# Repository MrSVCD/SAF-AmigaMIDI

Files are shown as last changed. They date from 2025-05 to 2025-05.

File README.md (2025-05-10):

# SAF-AmigaMIDI

## Not verified

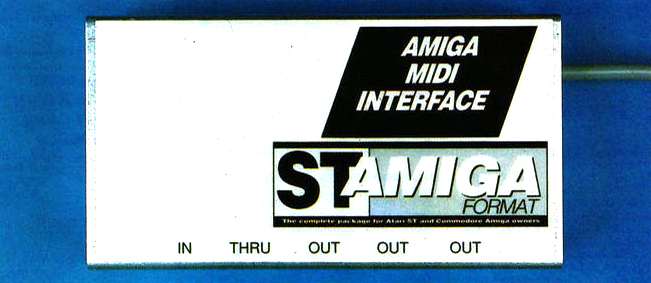
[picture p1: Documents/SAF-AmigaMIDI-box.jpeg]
Images


A somewhat faithful recreation of the Amiga MIDI interface from
"ST Amiga Format" issue 5

In the folder [CNC-version/](CNC-version/) is a mainly single sided design that
is targeting toner transfer, home photolithography and CNC milling. There are a
place for a optional L7805 voltage regulator. There are only two jumper wires in
this design that is shown as upper PCB layer.

Original article [Documents/SAF-AmigaMIDI.pdf](Documents/SAF-AmigaMIDI.pdf)

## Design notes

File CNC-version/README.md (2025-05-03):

# SAF-AmigaMIDI-CNC

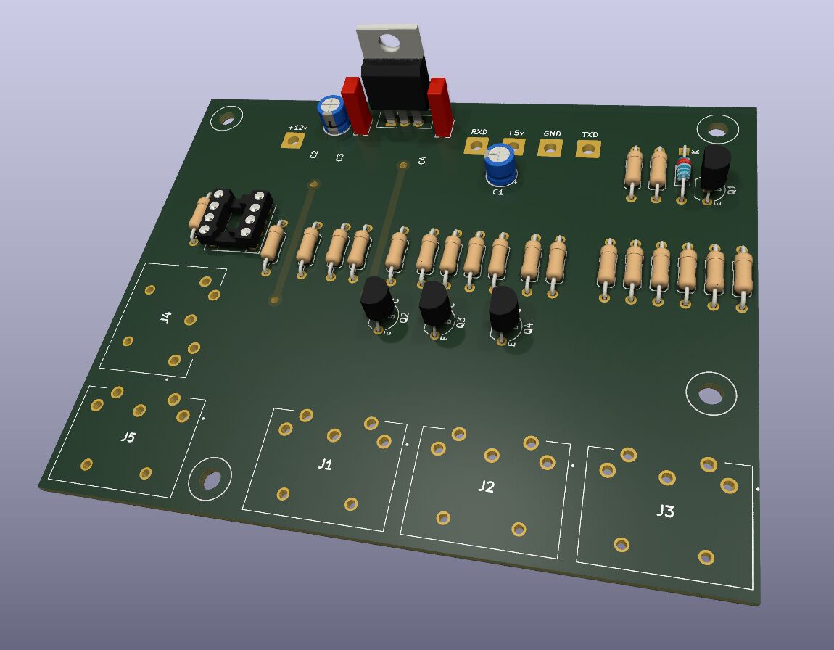
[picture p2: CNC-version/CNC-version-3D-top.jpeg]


This version is for making the midi interface at home.

It is single sided with two jumper wires (the wires is shown as the top copper
layer) there are also a optional voltage regulator spot.

It is also made to fit on a 100✕80mm, Half a Eurocard.

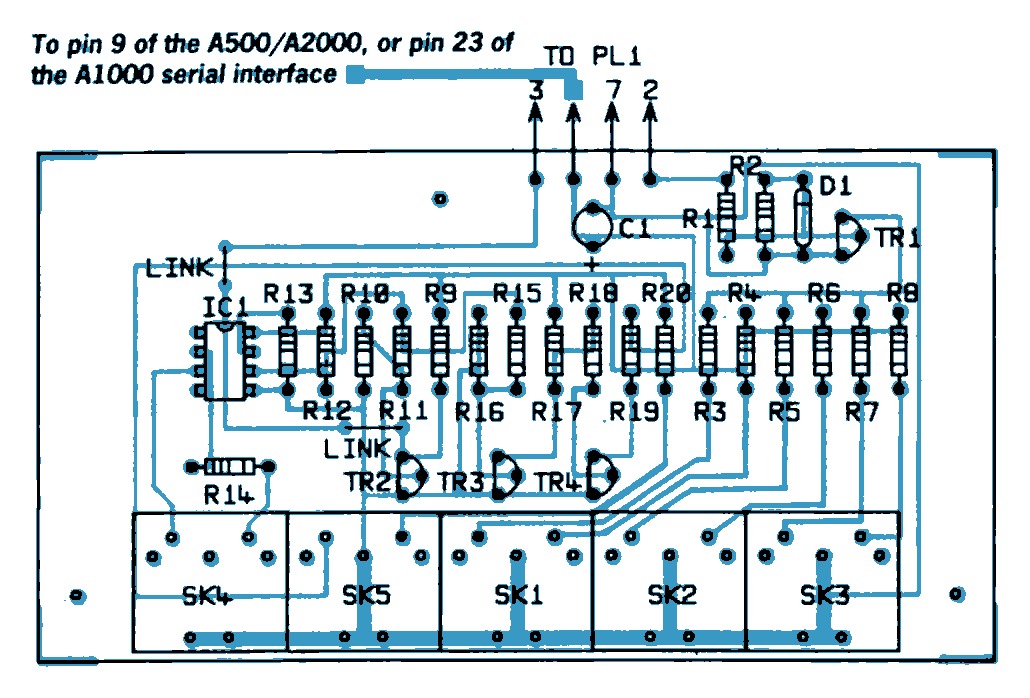
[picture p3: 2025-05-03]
Documents/SAF-AmigaMIDI-pcb.png

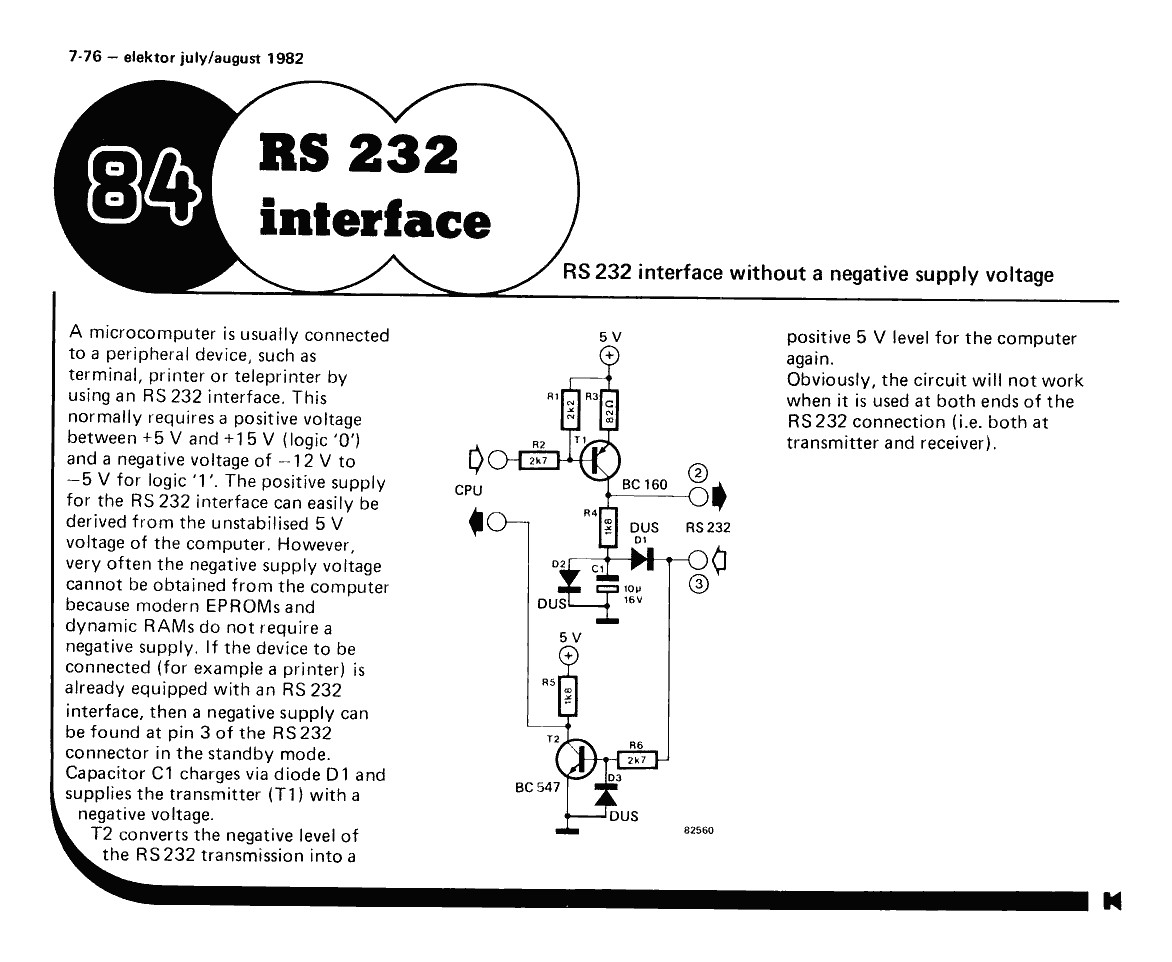
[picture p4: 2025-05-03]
Documents/Elektor_Y1982-I07-P076.png

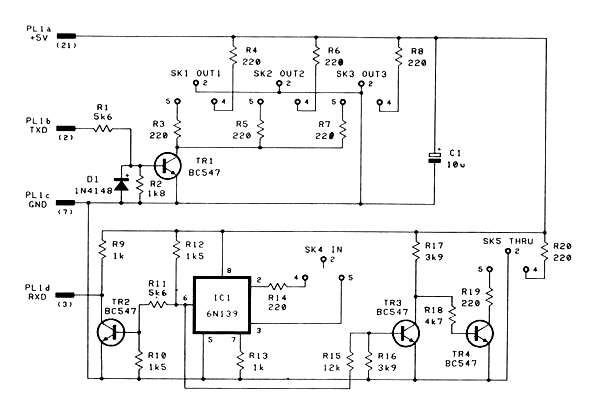
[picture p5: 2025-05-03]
Documents/SAF-AmigaMIDI-sch.png

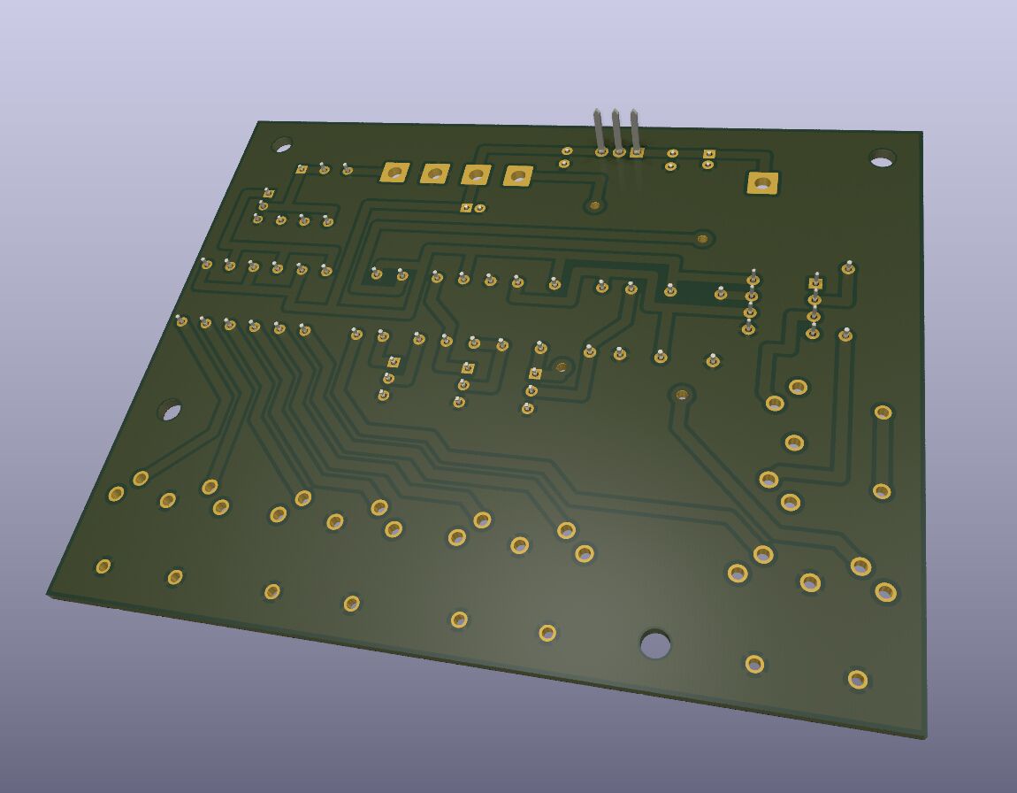
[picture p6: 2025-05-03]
CNC-version/CNC-version-3D-bottom.jpeg

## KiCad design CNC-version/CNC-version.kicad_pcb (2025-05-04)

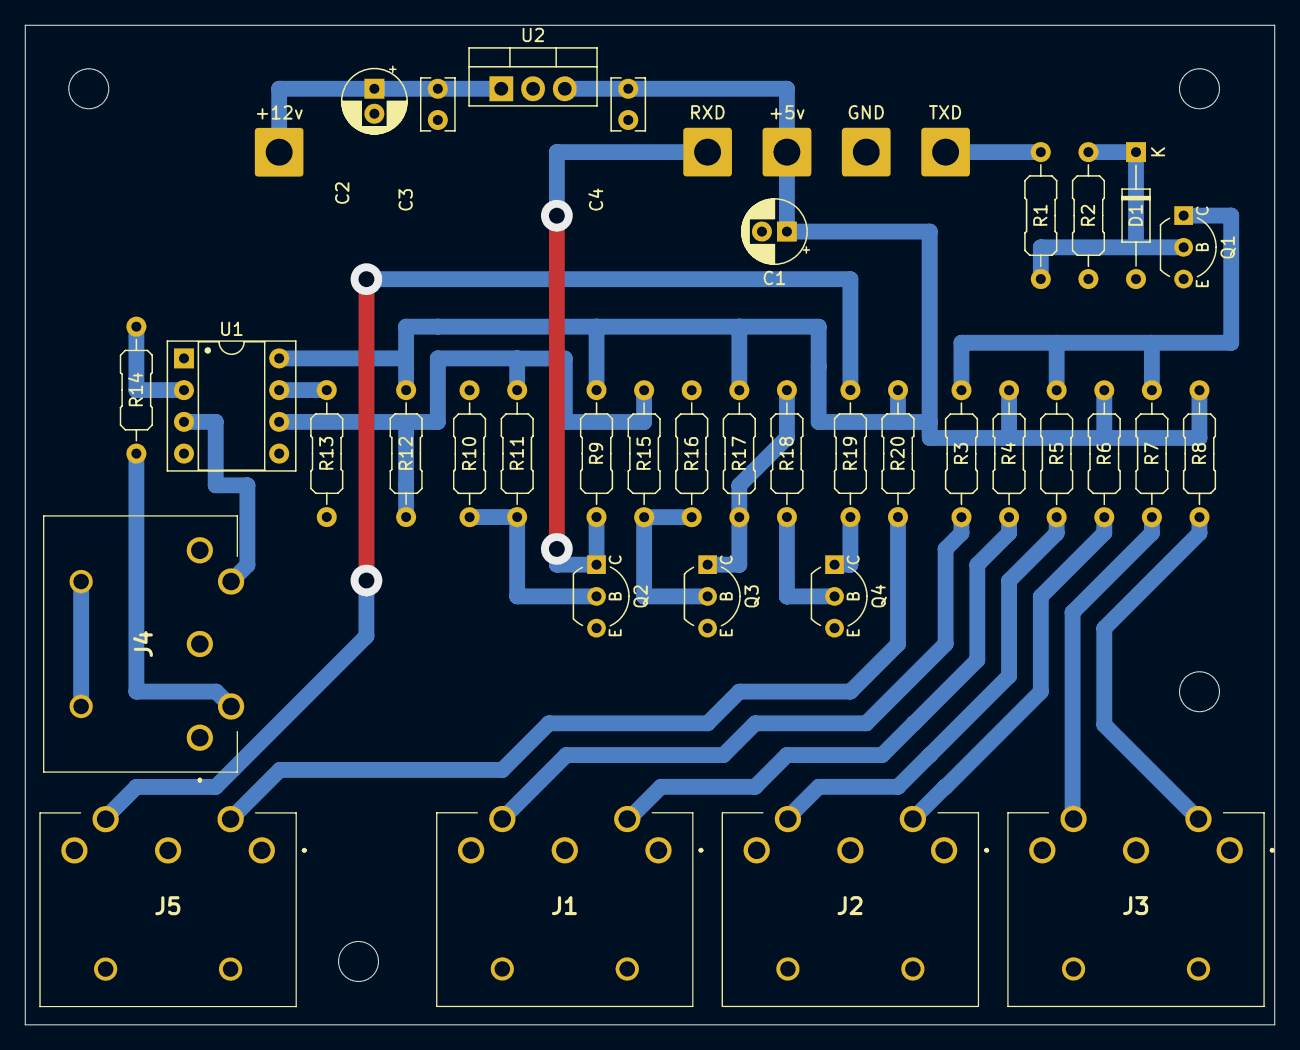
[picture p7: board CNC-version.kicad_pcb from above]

Board: 2 copper layers, 100.0 x 80.0 mm, 45 parts (0 on the bottom side), 26 nets.

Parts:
+5v, +12v: Conn_01x01; SolderWire-1.5sqmm_1x01_D1.7mm_OD3.9mm
C1, C2: 10µ 25v; CP_Radial_D5.0mm_P2.00mm
C3, C4: 100nF; C_Rect_L4.0mm_W2.5mm_P2.50mm
D1: 1N4148; D_DO-35_SOD27_P10.16mm_Horizontal
GND: Conn_01x01; SolderWire-1.5sqmm_1x01_D1.7mm_OD3.9mm
H1, H2, H3, H4: MountingHole; MountingHole_3.2mm_M3
J1, J2, J3, J4, J5: DIN-5_180degree; KCDX5SN
Q1, Q2, Q3, Q4: BC547; TO-92_Inline_Wide_CBE
R1, R11: 5k6; R_Axial_DIN0207_L6.3mm_D2.5mm_P10.16mm_Horizontal
R2: 1k8; R_Axial_DIN0207_L6.3mm_D2.5mm_P10.16mm_Horizontal
R3, R4, R5, R6, R7, R8, R14, R19, R20: 220R; R_Axial_DIN0207_L6.3mm_D2.5mm_P10.16mm_Horizontal
R9, R13: 1k; R_Axial_DIN0207_L6.3mm_D2.5mm_P10.16mm_Horizontal
R10, R12: 1k5; R_Axial_DIN0207_L6.3mm_D2.5mm_P10.16mm_Horizontal
R15: 12k; R_Axial_DIN0207_L6.3mm_D2.5mm_P10.16mm_Horizontal
R16, R17: 3k9; R_Axial_DIN0207_L6.3mm_D2.5mm_P10.16mm_Horizontal
R18: 4k7; R_Axial_DIN0207_L6.3mm_D2.5mm_P10.16mm_Horizontal
RXD: Conn_01x01; SolderWire-1.5sqmm_1x01_D1.7mm_OD3.9mm
TXD: Conn_01x01; SolderWire-1.5sqmm_1x01_D1.7mm_OD3.9mm
U1: 6N138; DIP-8_W7.62mm_Socket
U2: L7805; TO-220-3_Vertical

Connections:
+5V: +5v.1, C1.1, C4.1, R4.1, R6.1, R8.1, R9.1, R12.2, R17.1, R20.1, U1.8 (VCC), U2.3 (OUT)
GND: C1.2, C2.2, C3.2, C4.2, D1.2 (A), GND.1, J1.2, J1.MH1, J1.MH2, J2.2, J2.MH1, J2.MH2, J3.2, J3.MH1, J3.MH2, J5.2, J5.MH1, J5.MH2, Q1.3 (E), Q2.3 (E), Q3.3 (E), Q4.3 (E), R2.2, R10.2, R13.2, R16.2, U1.5 (GND), U2.2 (GND)
unnamed: +12v.1, C2.1, C3.1, U2.1 (IN)
unnamed: D1.1 (K), Q1.2 (B), R1.1, R2.1
unnamed: J1.4, R4.2
unnamed: J1.5, R3.1
unnamed: J2.4, R6.2
unnamed: J2.5, R5.1
unnamed: J3.4, R8.2
unnamed: J3.5, R7.1
unnamed: J4.4, R14.2
unnamed: J4.MH1, J4.MH2
unnamed: J5.4, R20.2
unnamed: J5.5, R19.2
unnamed: Q1.1 (C), R3.2, R5.2, R7.2
unnamed: Q2.2 (B), R10.1, R11.1
unnamed: Q2.1 (C), R9.2, RXD.1
unnamed: Q3.2 (B), R15.1, R16.1
unnamed: Q3.1 (C), R17.2, R18.1
unnamed: Q4.2 (B), R18.2
unnamed: Q4.1 (C), R19.1
unnamed: R1.2, TXD.1
unnamed: R14.1, U1.2 (C1)
unnamed: J4.5, U1.3 (C2)
unnamed: R13.1, U1.7 (VO1)
unnamed: R11.2, R12.1, R15.2, U1.6 (VO2)

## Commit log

2025-05-03 First CNC version
    [CNC-version.kicad_pcb, CNC-version.kicad_sch, PCB-house.kicad_pcb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]
2025-05-03 Update of CNC-version
    [CNC-version-B_Adhesive.gbr, CNC-version-B_Cu.gbr, CNC-version-B_Fab.gbr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]
2025-05-03 Getting there
    [PCB-house.kicad_pcb, PCB-house.kicad_sch]
2025-05-04 Too close for comfort
    [CNC-version.kicad_pcb]
2025-05-04 Even better layout
    [CNC-version.kicad_pcb]
2025-05-10 Clean Up
    [PCB-house.kicad_pcb, PCB-house.kicad_sch]
